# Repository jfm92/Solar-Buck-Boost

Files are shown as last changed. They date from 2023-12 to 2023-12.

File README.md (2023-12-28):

#Solar Buck-Boost

BoardPCB

Li-Po charging module with CN3063 and TPS63020 for solar and USB power, ensures constant voltage and efficiency. By default it's configure to ouput 3.3v with power saving mode off.

**Important you can use a solar panel with a maximum of 6V and minimum of 4.4v, but it's recommendable to use 5V solar panel modules**

## Configuration:

This modules allows to set the output voltage an working mode by doing some little modifications.

BoardLayout

## Output Voltage:

This module allows to set an ouput voltage by changing R4 resistor. By default it's 1M giving an ouput of 3.3v, but you can get the following ouput values.

| VOUT  | R4 |
|---|---|
| 2.5V  | 750K |
| 3.3V  | 1M |
| 3.6V  | 1.1M |
| 4.5V  | 1.43M  |
| 5V | 1.6M |

## Power saving mode:

- Power saving mode on: Join R8.
- Power saving mode off: Join R7.

## Schematics:

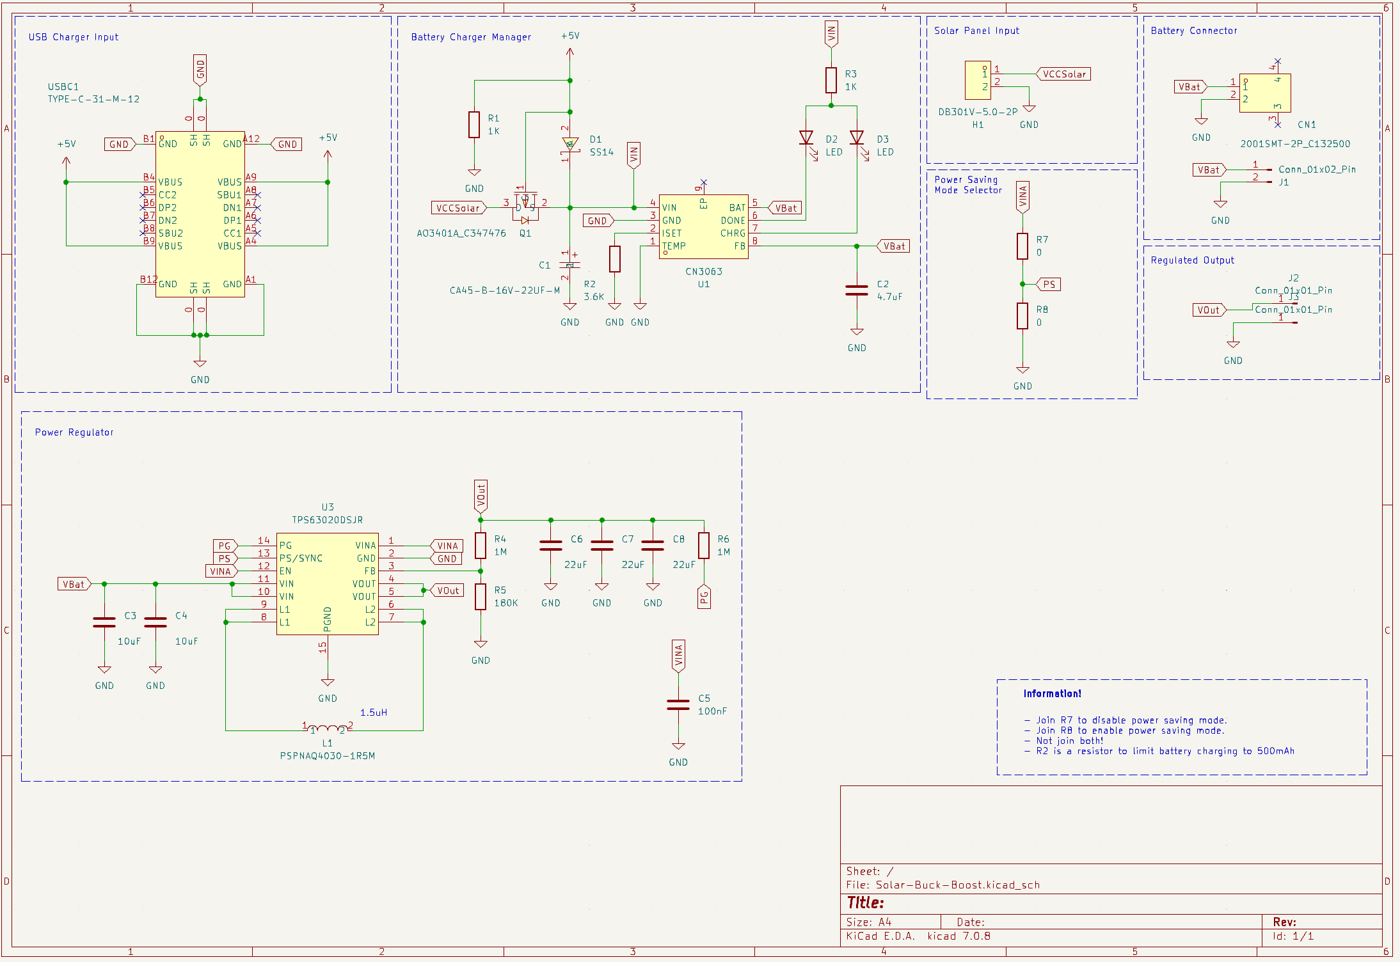
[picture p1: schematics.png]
Schematics


## PCB:

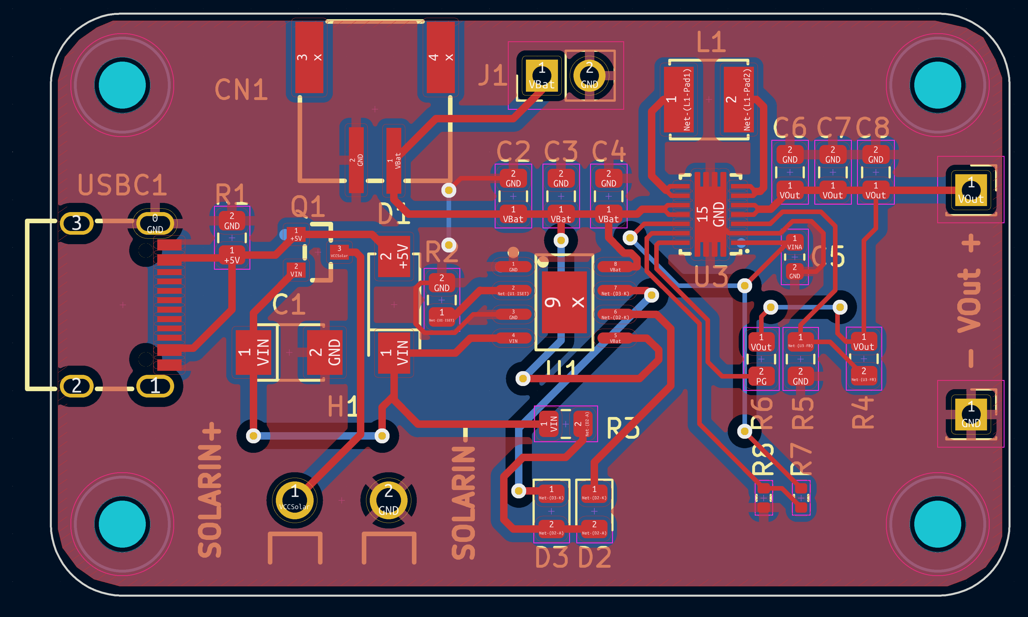
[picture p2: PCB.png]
PCB


## Bill of materials:

You can find a list of material with a link to the crucial one.

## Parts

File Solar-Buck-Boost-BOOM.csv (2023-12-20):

Reference | Value | Footprint | Datasheet | LCSC Part | Cdad
C1 | CA45-B-16V-22UF-M | easyeda2kicad:CAP-SMD_L3.5-W2.8-R-RD | https://lcsc.com/product-detail/Tantalum-Capacitors_22uF-226-20-16V_C140371.html | C140371 | 1
C2 | 4.7uF | Capacitor_SMD:C_0805_2012Metric | ~ |  | 1
C3, C4 | 10uF | Capacitor_SMD:C_0805_2012Metric | ~ |  | 2
C5 | 100nF | Capacitor_SMD:C_0603_1608Metric | ~ |  | 1
C6-C8 | 22uF | Capacitor_SMD:C_0805_2012Metric | ~ |  | 3
CN1 | 2001SMT-2P_C132500 | easyeda2kicad:CONN-SMD_2001SMT-2P-WT | https://lcsc.com/product-detail/PH-Connectors_Shenzhen-Cancome-2001series-socket-1-2P-2mm_C132500.html | C132500 | 1
D1 | SS14 | easyeda2kicad:SMA_L4.2-W2.6-LS5.3-RD | https://lcsc.com/product-detail/Schottky-Barrier-Diodes-SBD_SS14_C2480.html | C2480 | 1
D2, D3 | LED | LED_SMD:LED_0805_2012Metric | ~ |  | 2
H1 | DB301V-5.0-2P | easyeda2kicad:CONN-TH_2P-P5.00_L7.6-W10.0 | https://lcsc.com/product-detail/Screw-terminal_DIBO-DB301V-5-0-2P_C395882.html | C395882 | 1
J1 | Conn_01x02_Pin | Connector_PinHeader_2.54mm:PinHeader_1x02_P2.54mm_Vertical | ~ |  | 1
J2, J3 | Conn_01x01_Pin | Connector_PinSocket_2.54mm:PinSocket_1x01_P2.54mm_Vertical | ~ |  | 2
L1 | PSPNAQ4030-1R5M | easyeda2kicad:IND-SMD_L4.0-W4.0 |  | C436670 | 1
Q1 | AO3401A_C347476 | easyeda2kicad:SOT-23_L2.9-W1.3-P1.90-LS2.4-BR | https://lcsc.com/product-detail/Others_Youtai-Semiconductor-Co-Ltd-AO3401A-4-1A_C347476.html | C347476 | 1
R1, R3 | 1K | Resistor_SMD:R_0805_2012Metric | ~ |  | 2
R2 | 3.6K | Resistor_SMD:R_0805_2012Metric | ~ |  | 1
R4, R6 | 1M | Resistor_SMD:R_0805_2012Metric | ~ |  | 2
R5 | 180K | Resistor_SMD:R_0805_2012Metric | ~ |  | 1
R7, R8 | 0 | Resistor_SMD:R_0402_1005Metric | ~ |  | 2
U1 | CN3063 | easyeda2kicad:SOIC-8_L4.9-W3.9-P1.27-LS6.0-BL-EP3.3-1 | https://lcsc.com/product-detail/PMIC-AC-DC-Converters_CN3063_C28078.html | C28078 | 1
U3 | TPS63020DSJR | easyeda2kicad:VSON-14_L4.0-W3.0-P0.50-BL-EP_TI_DSJ | https://lcsc.com/product-detail/DC-DC-Converters_TI_TPS63020DSJR_TPS63020DSJR_C15483.html | C15483 | 1
USBC1 | TYPE-C-31-M-12 | easyeda2kicad:USB-C_SMD-TYPE-C-31-M-12 | https://lcsc.com/product-detail/USB-Type-C_Korean-Hroparts-Elec-TYPE-C-31-M-12_C165948.html | C165948 | 1

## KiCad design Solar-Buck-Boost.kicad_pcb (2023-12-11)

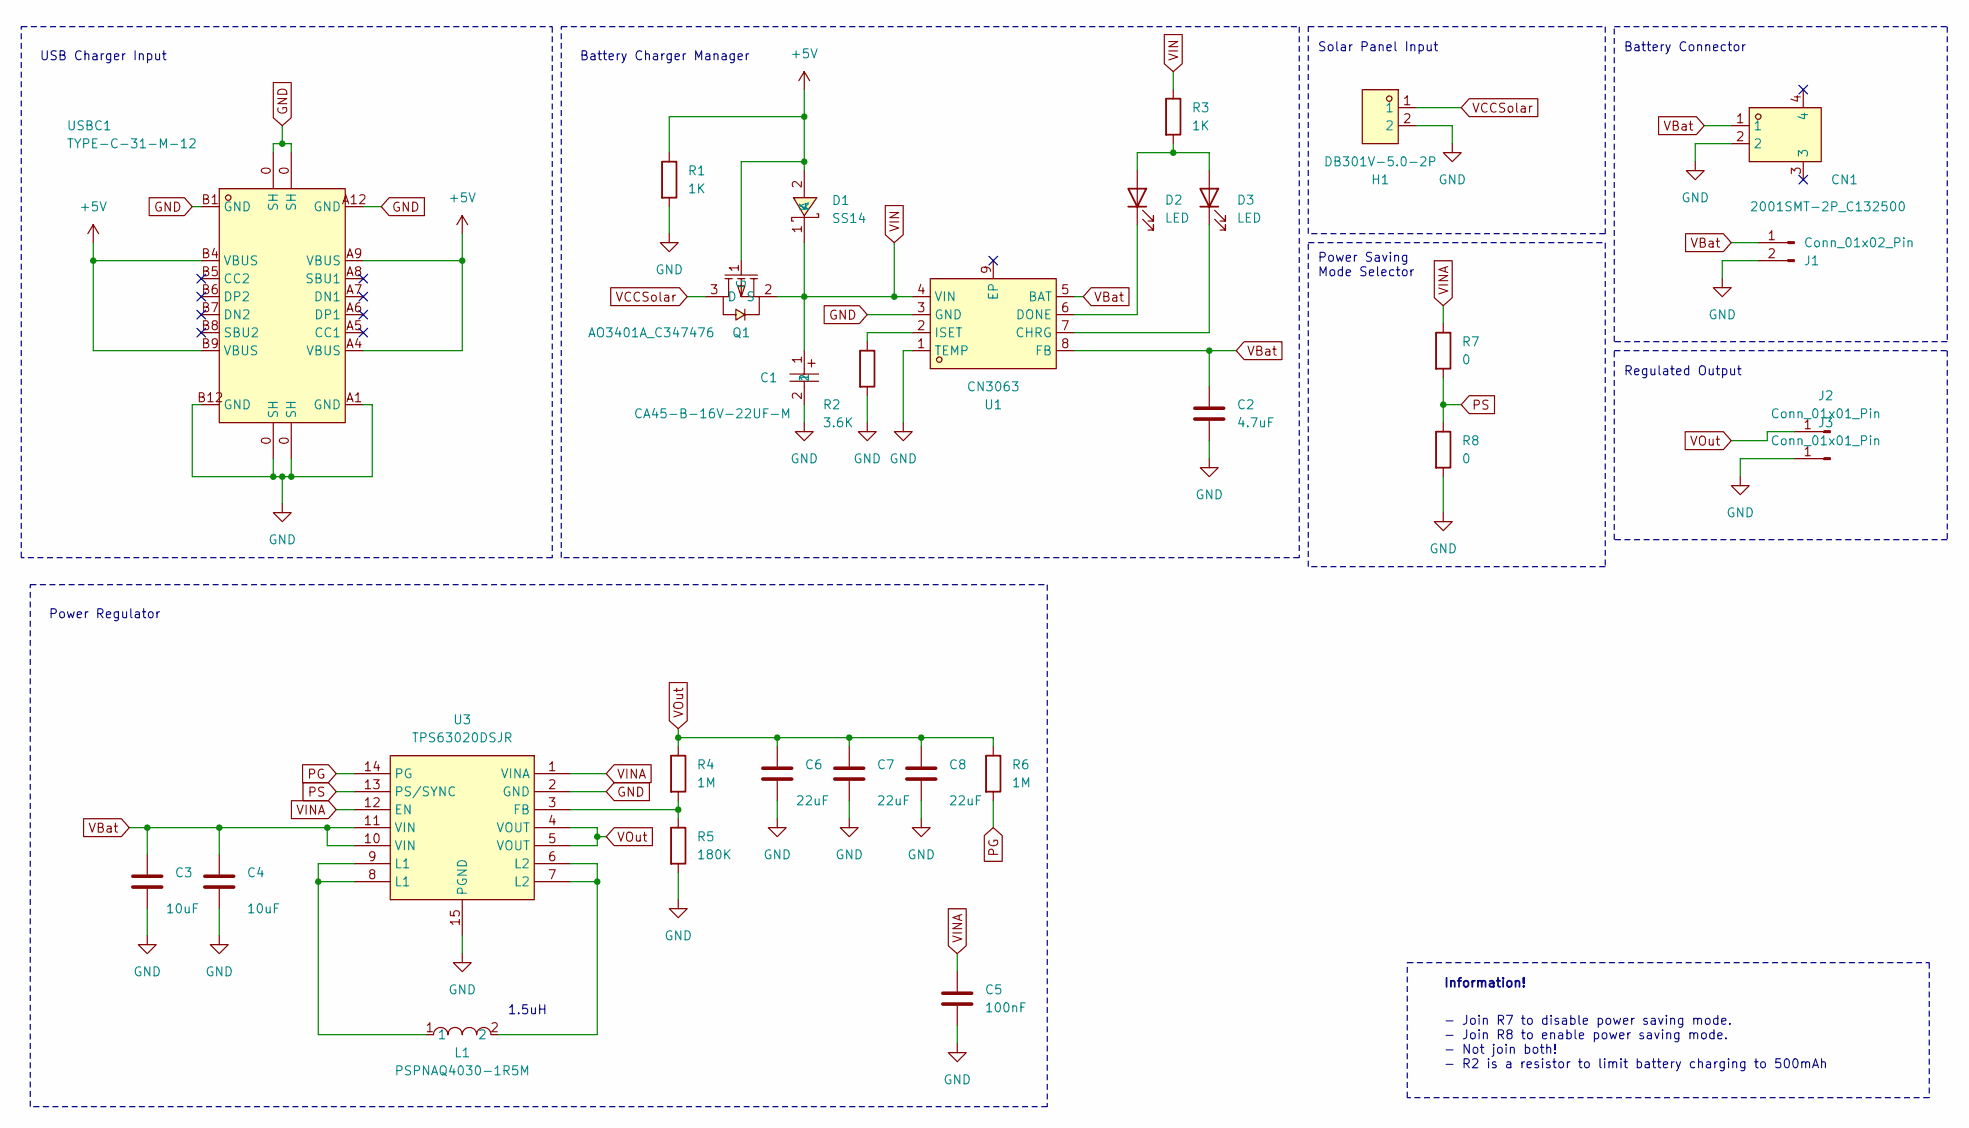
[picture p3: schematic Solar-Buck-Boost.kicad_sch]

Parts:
C1: CA45-B-16V-22UF-M; CAP-SMD_L3.5-W2.8-R-RD; LCSC Part C140371
C2: 4.7uF; C_0805_2012Metric
C3, C4: 10uF; C_0805_2012Metric
C5: 100nF; C_0603_1608Metric
C6, C7, C8: 22uF; C_0805_2012Metric
CN1: 2001SMT-2P_C132500; CONN-SMD_2001SMT-2P-WT; LCSC Part C132500
D1: SS14; SMA_L4.2-W2.6-LS5.3-RD; LCSC Part C2480
D2, D3: LED; LED_0805_2012Metric
H1: DB301V-5.0-2P; CONN-TH_2P-P5.00_L7.6-W10.0; LCSC Part C395882
J1: Conn_01x02_Pin; PinHeader_1x02_P2.54mm_Vertical
J2, J3: Conn_01x01_Pin; PinSocket_1x01_P2.54mm_Vertical
L1: PSPNAQ4030-1R5M; IND-SMD_L4.0-W4.0; LCSC Part C436670
Q1: AO3401A_C347476; SOT-23_L2.9-W1.3-P1.90-LS2.4-BR; LCSC Part C347476
R1, R3: 1K; R_0805_2012Metric
R2: 3.6K; R_0805_2012Metric
R4, R6: 1M; R_0805_2012Metric
R5: 180K; R_0805_2012Metric
R7, R8: 0; R_0402_1005Metric
U1: CN3063; SOIC-8_L4.9-W3.9-P1.27-LS6.0-BL-EP3.3-1; LCSC Part C28078
U3: TPS63020DSJR; VSON-14_L4.0-W3.0-P0.50-BL-EP_TI_DSJ; LCSC Part C15483
USBC1: TYPE-C-31-M-12; USB-C_SMD-TYPE-C-31-M-12; LCSC Part C165948

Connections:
+5V: D1.2 (A), Q1.1 (G), R1.1, USBC1.A4 (VBUS), USBC1.A9 (VBUS), USBC1.B4 (VBUS), USBC1.B9 (VBUS)
GND: C1.2, C2.2, C3.2, C4.2, C5.2, C6.2, C7.2, C8.2, CN1.2, H1.2, J1.2, J3.1, R1.2, R2.2, R5.2, R8.2, U1.1 (TEMP), U1.3 (GND), U3.2 (GND), U3.15 (PGND), USBC1.0 (SH), USBC1.A1 (GND), USBC1.A12 (GND), USBC1.B1 (GND), USBC1.B12 (GND)
unnamed: D2.2 (A), D3.2 (A), R3.2
unnamed: D2.1 (K), U1.6 (DONE)
unnamed: D3.1 (K), U1.7 (CHRG)
unnamed: L1.1, U3.8 (L1), U3.9 (L1)
unnamed: L1.2, U3.6 (L2), U3.7 (L2)
unnamed: R2.1, U1.2 (ISET)
unnamed: R4.2, R5.1, U3.3 (FB)
PG: R6.2, U3.14 (PG)
PS: R7.2, R8.1, U3.13 (PS/SYNC)
VBat: C2.1, C3.1, C4.1, CN1.1, J1.1, U1.5 (BAT), U1.8 (FB), U3.10 (VIN), U3.11 (VIN)
VCCSolar: H1.1, Q1.3 (D)
VIN: C1.1, D1.1 (K), Q1.2 (S), R3.1, U1.4 (VIN)
VINA: C5.1, R7.1, U3.1 (VINA), U3.12 (EN)
VOut: C6.1, C7.1, C8.1, J2.1, R4.1, R6.1, U3.4 (VOUT), U3.5 (VOUT)

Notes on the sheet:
Power Regulator
Battery Charger Manager
Regulated Output
USB Charger Input
Power Saving Mode Selector
- Join R7 to disable power saving mode. - Join R8 to enable power saving mode. - Not join both! - R2 is a resistor to limit battery charging to 500mAh
Information!
Battery Connector
1.5uH
Solar Panel Input

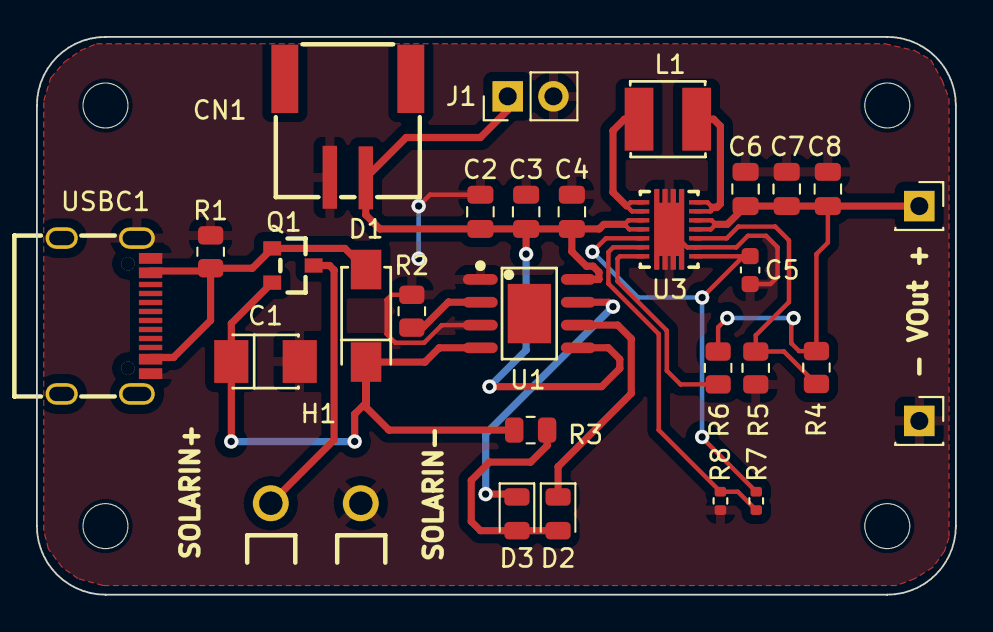
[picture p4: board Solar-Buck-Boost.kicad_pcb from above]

Board: 2 copper layers, 51.1 x 31.0 mm, 29 parts (0 on the bottom side), 16 nets.

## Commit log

2023-12-11 Adding Solar-Buck Boots KiCad Project
    [Solar-Buck-Boost.kicad_pcb, Solar-Buck-Boost.kicad_sch]
2023-12-12 Schematics fix
    [Solar-Buck-Boost.kicad_sch]
2023-12-12 Adding schematics image
2023-12-20 Adding documentation
    [Solar-Buck-Boost-BOOM.csv]
